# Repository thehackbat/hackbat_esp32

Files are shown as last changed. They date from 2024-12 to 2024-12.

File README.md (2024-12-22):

# HACKBAT ESP32 

New version of the Hackbat tool, this time based on the ESP32 C6. 

> NOTE: This version is still under test, so minor changes can be applied.

## The CPU

The new version of hackbat features a powerful [ESP32C6](https://www.espressif.com/en/products/socs/esp32-c6) from [Espressif](https://www.espressif.com). This microcontroller features a dual core RISC-V processor, WIFI6, BT LE and a bunch of peripherals. 

The package used is the WROOM-1, but it is also compatible with the 1U model adding an external antenna.

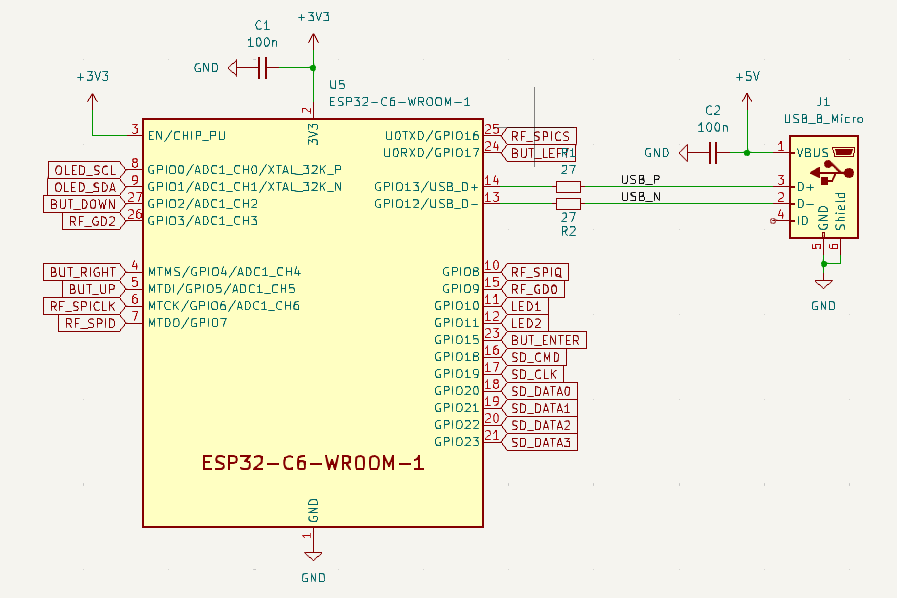
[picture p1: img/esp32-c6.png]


## RF

Like the original, the Hackbat ESP32 features an RF tranceiver, the [CC1101](https://www.ti.com/product/es-mx/CC1101) from Texas Instruments. 

The CC1101 is a low-cost sub-1 GHz transceiver designed for very low-power wireless applications. The circuit is mainly intended for the ISM (Industrial, Scientific and Medical) and SRD (Short Range Device) frequency bands at 315, 433, 868, and 915 MHz, but can easily be programmed for operation at other frequencies in the 300-348 MHz, 387-464 MHz and 779-928 MHz bands

The Hackbat ESP32 board includes an antenna, but can be also populate the J2 connector in order to add an SMA antenna.

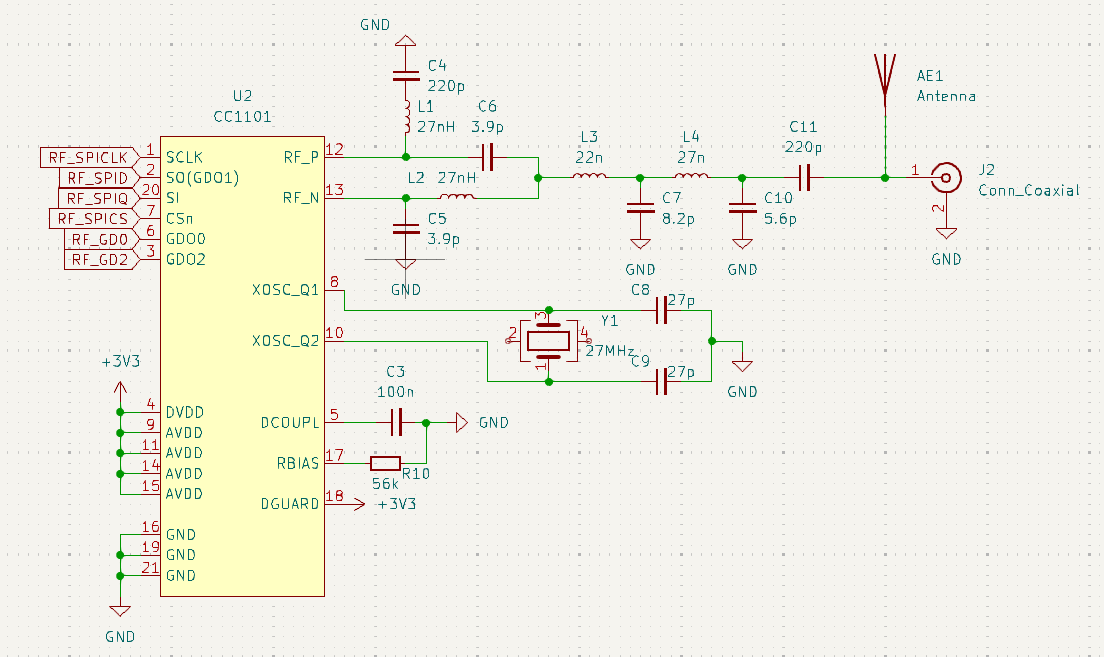
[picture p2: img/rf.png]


## OLED

A monochrome OLED is added as an interface. The driver used in the ESP-IDF IDE is able to work with the SH1106, and ssd1306

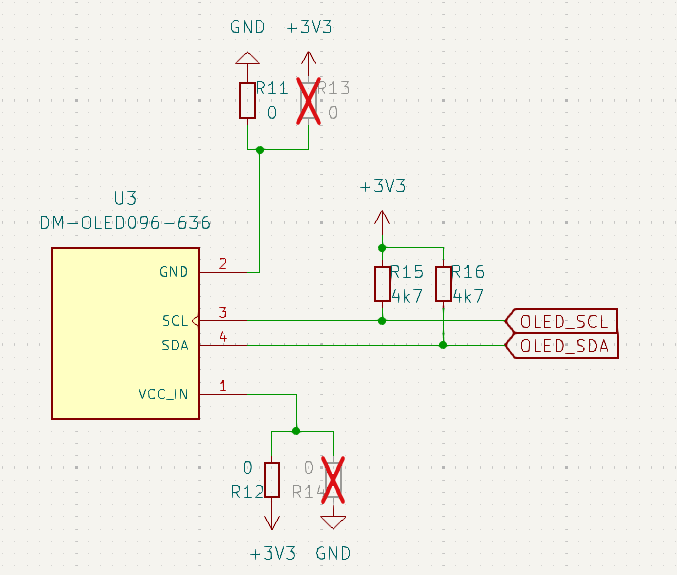
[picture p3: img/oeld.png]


## SDCard

The SD Card in this version uses the SDIO interface with the microcontroller, so the speed is increased with respect the first version of the board.

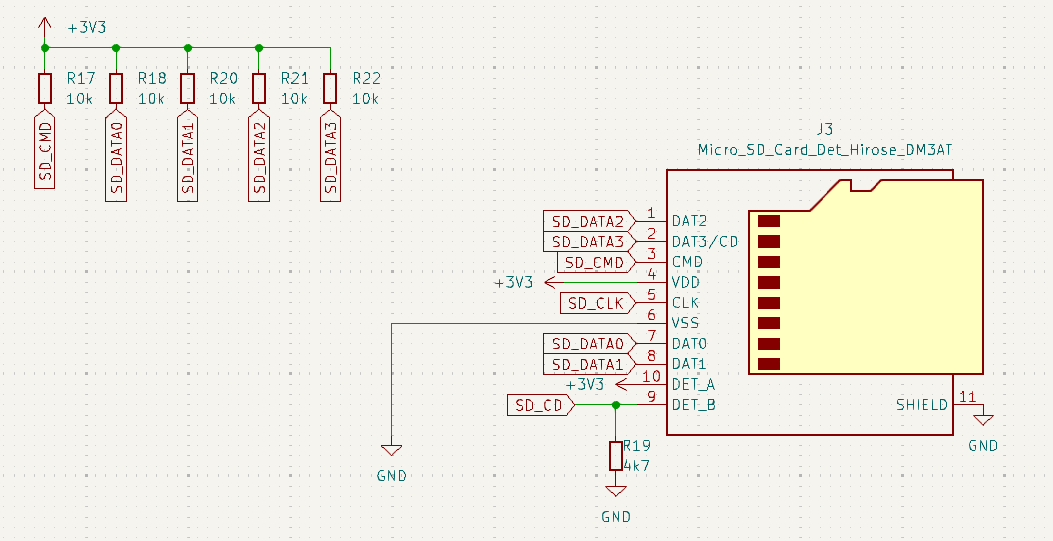
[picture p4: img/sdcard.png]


## Layout

The layout of the board is 2-layer with components in both layers.

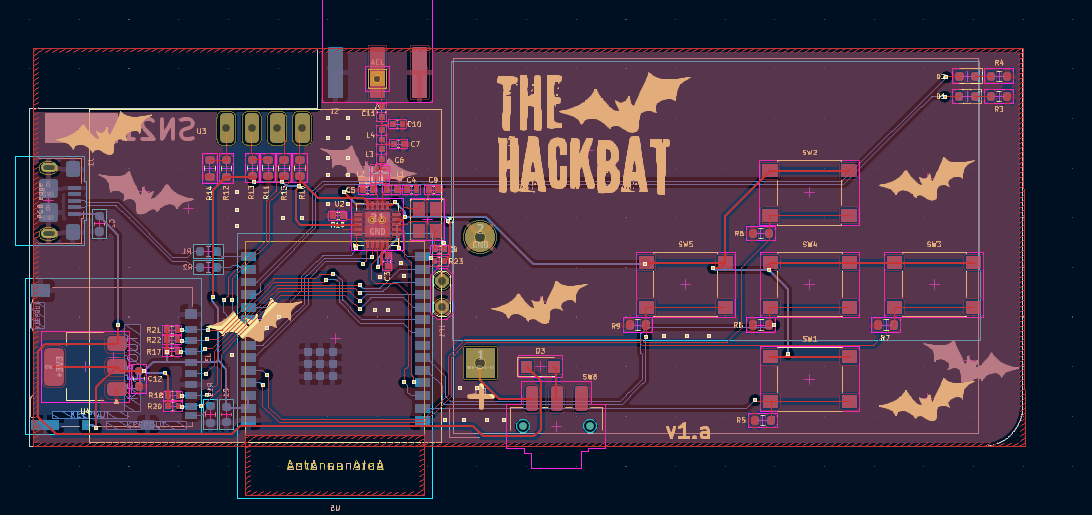
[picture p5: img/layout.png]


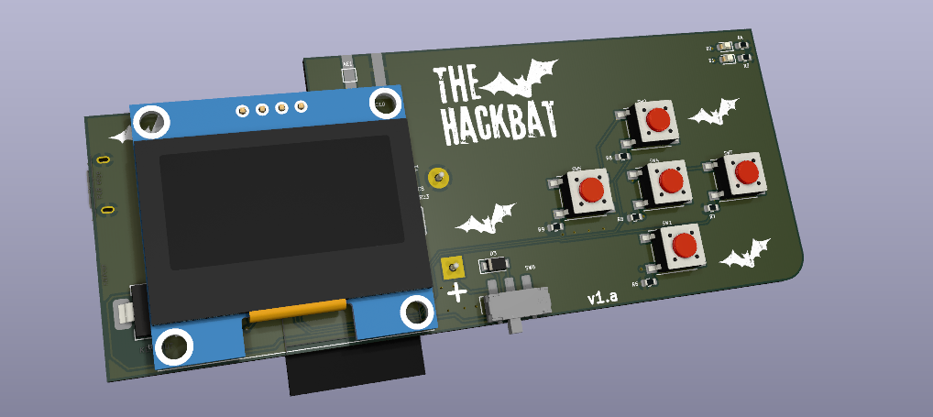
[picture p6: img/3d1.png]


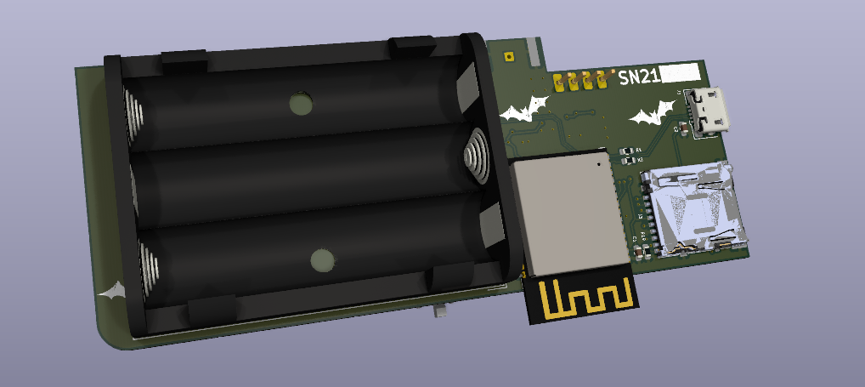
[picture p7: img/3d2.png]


## Get yours

This project is open-source so you can build your own Hackbat by sending the production files to [JLCPCB](https://jlcpcb.com/?from=controlpath).

[JLCPCB](https://jlcpcb.com/?from=controlpath) not only will manufacture your PCB, but they can also asembly your board. To do that, you have to use the BOM and the Centroid files provided in the [`production_files`](./kicad/production_files/) folder.

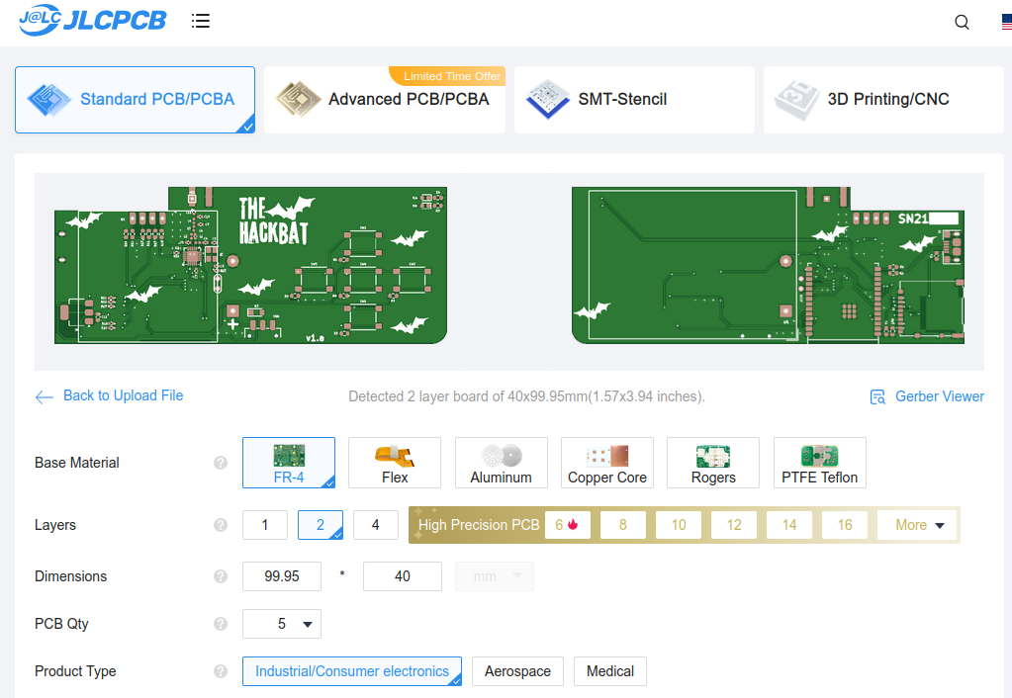
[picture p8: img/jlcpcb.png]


Remember to change the Surface Finish to LeadFree HASL to make your board ROHS compliant. Also, the original board uses a Black PCB color, so if you want to keep your Hackbat like the original, you can select this color to be sure that the silkscreen is seen correctly.

In a few days, you will receive your board at home.

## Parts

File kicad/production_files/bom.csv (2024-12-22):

Reference | Value | Footprint | Qty | DNP | JLCPCB Part #
C1,C2 | 100n | Capacitor_SMD:C_0603_1608Metric | 2
C3 | 100n | Capacitor_SMD:C_0402_1005Metric | 1
C4,C11 | 220p | Capacitor_SMD:C_0402_1005Metric | 2
C5,C6 | 3.9p | Capacitor_SMD:C_0402_1005Metric | 2
C7 | 8.2p | Capacitor_SMD:C_0402_1005Metric | 1
C8,C9 | 27p | Capacitor_SMD:C_0402_1005Metric | 2
C10 | 5.6p | Capacitor_SMD:C_0402_1005Metric | 1
C12 | 1u | Capacitor_SMD:C_0603_1608Metric | 1
D1,D2 | LED | LED_SMD:LED_0603_1608Metric | 2
D3 | D_Schottky | Diode_SMD:Nexperia_CFP3_SOD-123W | 1 |  | C82544
J1 | USB_B_Micro | Connector_USB:USB_Micro-B_Amphenol_10118193-0001LF_Horizontal | 1
J2 | Conn_Coaxial | Connector_Coaxial:SMA_Amphenol_132289_EdgeMount | 1
J3 | Micro_SD_Card_Det_Hirose_DM3AT | Connector_Card:microSD_HC_Hirose_DM3AT-SF-PEJM5 | 1 |  | C114218
JP1 | Jumper_2_Open | TestPoint:TestPoint_2Pads_Pitch2.54mm_Drill0.8mm | 1
L1,L2 | 27nH | Inductor_SMD:L_0402_1005Metric | 2
L3 | 22n | Inductor_SMD:L_0402_1005Metric | 1
L4 | 27n | Inductor_SMD:L_0402_1005Metric | 1
R1,R2 | 27 | Resistor_SMD:R_0603_1608Metric | 2
R3,R4,R5,R6,R7,R8,R9,R15,R16,R19 | 4k7 | Resistor_SMD:R_0603_1608Metric | 10
R10 | 56k | Resistor_SMD:R_0402_1005Metric | 1
R11,R12 | 0 | Resistor_SMD:R_0603_1608Metric | 2
R17,R18,R20,R21,R22,R23 | 10k | Resistor_SMD:R_0402_1005Metric | 6
SW1,SW2,SW3,SW4,SW5 | SW_Push | Button_Switch_SMD:SW_Push_1P1T_NO_6x6mm_H9.5mm | 5 |  | C455109
SW6 | SW_SPST | Button_Switch_SMD:SW_SPDT_CK_JS102011SAQN | 1 |  | C92658
U2 | CC1101 | Package_DFN_QFN:QFN-20-1EP_4x4mm_P0.5mm_EP2.6x2.6mm_ThermalVias | 1 |  | C29953
U4 | AMS1117-3.3 | Package_TO_SOT_SMD:SOT-223-3_TabPin2 | 1
Y1 | 27MHz | Crystal:Crystal_SMD_3225-4Pin_3.2x2.5mm | 1 |  | C254353

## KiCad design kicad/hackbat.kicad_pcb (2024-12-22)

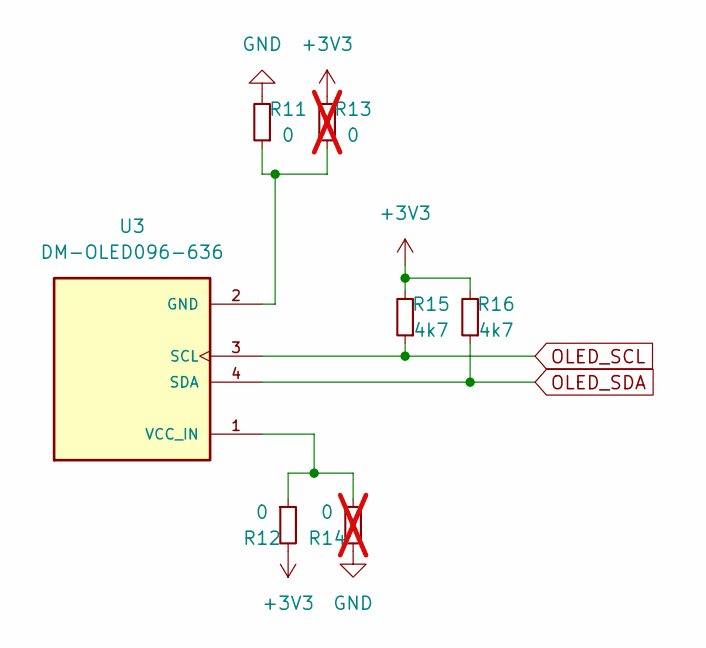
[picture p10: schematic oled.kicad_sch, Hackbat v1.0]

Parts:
R11, R12: 0; R_0603_1608Metric
R13, R14: 0; R_0603_1608Metric; not fitted
R15, R16: 4k7; R_0603_1608Metric
U3: DM-OLED096-636; oled_1.3; PARTREV 2018-09-10

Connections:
+3V3: R12.2, R13.2, R15.2, R16.2; also elsewhere on the board
GND: R11.2, R14.2; also elsewhere on the board
unnamed: R11.1, R13.1, U3.2 (GND)
unnamed: R12.1, R14.1, U3.1 (VCC_IN)
OLED_SCL: R15.1, U3.3 (SCL); also elsewhere on the board
OLED_SDA: R16.1, U3.4 (SDA); also elsewhere on the board

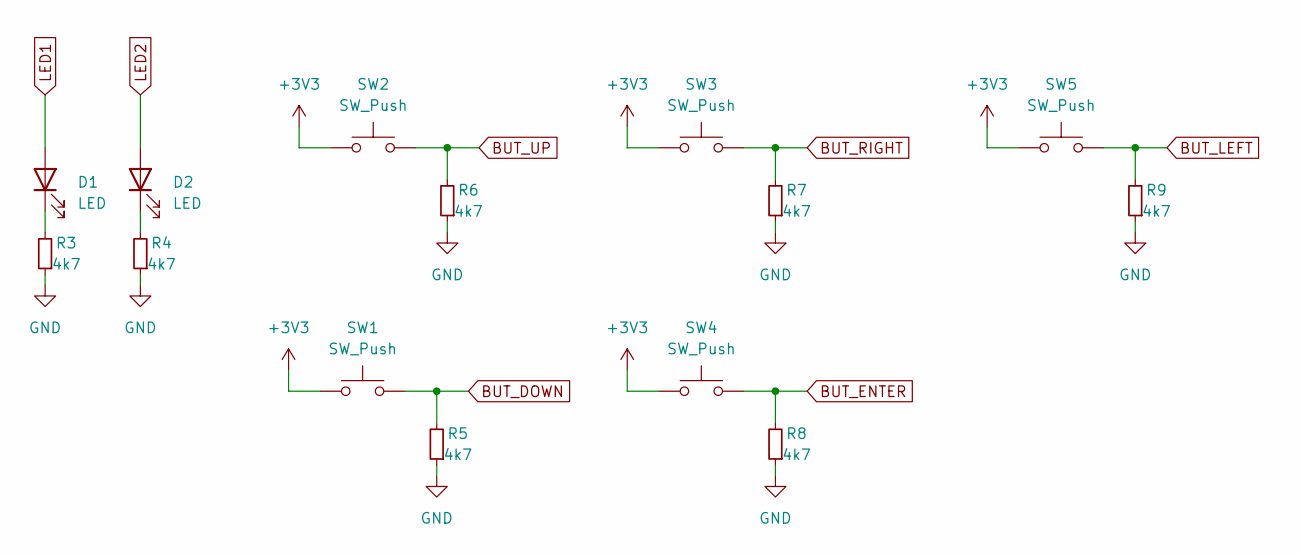
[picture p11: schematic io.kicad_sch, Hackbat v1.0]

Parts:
D1, D2: LED; LED_0603_1608Metric
R3, R4, R5, R6, R7, R8, R9: 4k7; R_0603_1608Metric
SW1, SW2, SW3, SW4, SW5: SW_Push; SW_Push_1P1T_NO_6x6mm_H9.5mm; JLCPCB Part # C455109

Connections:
+3V3: SW1.1, SW2.1, SW3.1, SW4.1, SW5.1; also elsewhere on the board
BUT_DOWN: R5.2, SW1.2; also elsewhere on the board
BUT_ENTER: R8.2, SW4.2; also elsewhere on the board
BUT_LEFT: R9.2, SW5.2; also elsewhere on the board
BUT_RIGHT: R7.2, SW3.2; also elsewhere on the board
BUT_UP: R6.2, SW2.2; also elsewhere on the board
GND: R3.1, R4.1, R5.1, R6.1, R7.1, R8.1, R9.1; also elsewhere on the board
LED1: D1.2 (A); also elsewhere on the board
LED2: D2.2 (A); also elsewhere on the board
unnamed: D1.1 (K), R3.2
unnamed: D2.1 (K), R4.2

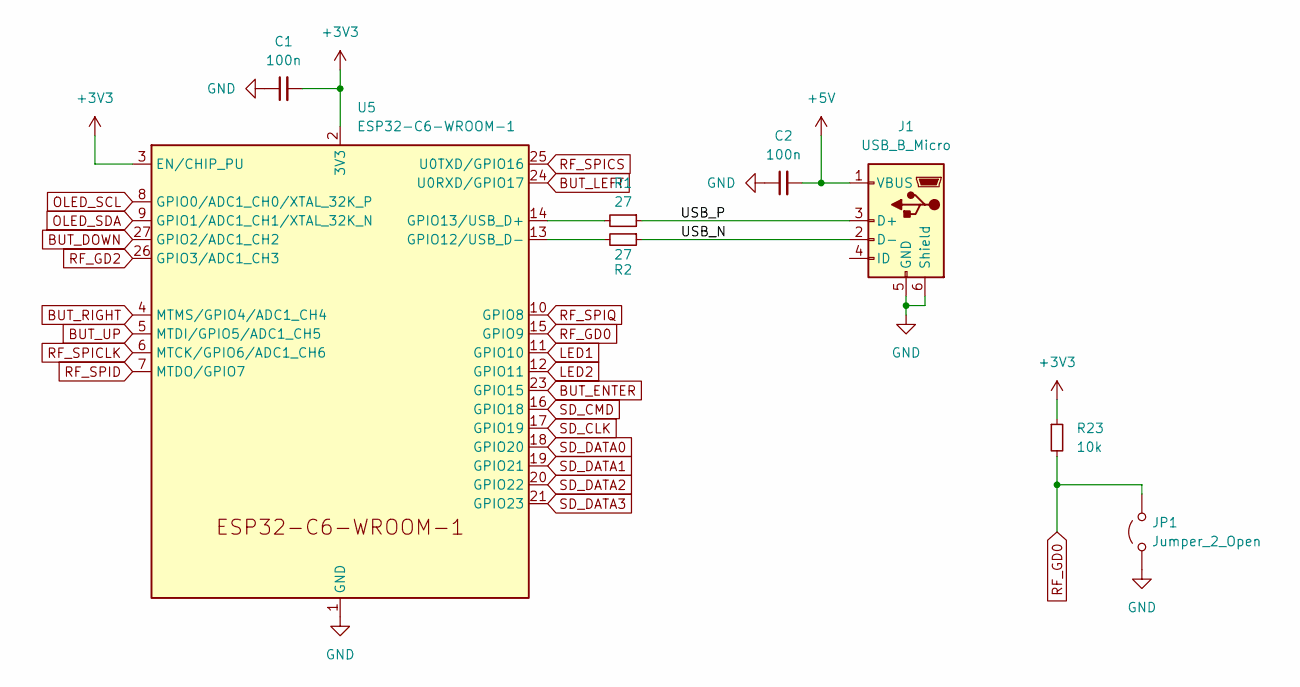
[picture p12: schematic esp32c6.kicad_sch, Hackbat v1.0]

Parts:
C1, C2: 100n; C_0603_1608Metric
J1: USB_B_Micro; USB_Micro-B_Amphenol_10118193-0001LF_Horizontal
JP1: Jumper_2_Open; TestPoint_2Pads_Pitch2.54mm_Drill0.8mm
R1, R2: 27; R_0603_1608Metric
R23: 10k; R_0402_1005Metric
U5: ESP32-C6-WROOM-1

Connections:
+3V3: C1.2, R23.1, U5.2 (3V3), U5.3 (EN/CHIP_PU); also elsewhere on the board
+5V: C2.2, J1.1 (VBUS); also elsewhere on the board
/esp32c6/USB_N: J1.2 (D-), R2.1
/esp32c6/USB_P: J1.3 (D+), R1.1
BUT_DOWN: U5.27 (GPIO2/ADC1_CH2); also elsewhere on the board
BUT_ENTER: U5.23 (GPIO15); also elsewhere on the board
BUT_LEFT: U5.24 (U0RXD/GPIO17); also elsewhere on the board
BUT_RIGHT: U5.4 (MTMS/GPIO4/ADC1_CH4); also elsewhere on the board
BUT_UP: U5.5 (MTDI/GPIO5/ADC1_CH5); also elsewhere on the board
GND: C1.1, C2.1, J1.5 (GND), J1.6 (Shield), JP1.1 (A), U5.1 (GND), U5.28 (GND), U5.29 (GND); also elsewhere on the board
LED1: U5.11 (GPIO10); also elsewhere on the board
LED2: U5.12 (GPIO11); also elsewhere on the board
unnamed: R2.2, U5.13 (GPIO12/USB_D-)
unnamed: R1.2, U5.14 (GPIO13/USB_D+)
OLED_SCL: U5.8 (GPIO0/ADC1_CH0/XTAL_32K_P); also elsewhere on the board
OLED_SDA: U5.9 (GPIO1/ADC1_CH1/XTAL_32K_N); also elsewhere on the board
RF_GD0: JP1.2 (B), R23.2, U5.15 (GPIO9); also elsewhere on the board
RF_GD2: U5.26 (GPIO3/ADC1_CH3); also elsewhere on the board
RF_SPICLK: U5.6 (MTCK/GPIO6/ADC1_CH6); also elsewhere on the board
RF_SPICS: U5.25 (U0TXD/GPIO16); also elsewhere on the board
RF_SPID: U5.7 (MTDO/GPIO7); also elsewhere on the board
RF_SPIQ: U5.10 (GPIO8); also elsewhere on the board
SD_CLK: U5.17 (GPIO19); also elsewhere on the board
SD_CMD: U5.16 (GPIO18); also elsewhere on the board
SD_DATA0: U5.18 (GPIO20); also elsewhere on the board
SD_DATA1: U5.19 (GPIO21); also elsewhere on the board
SD_DATA2: U5.20 (GPIO22); also elsewhere on the board
SD_DATA3: U5.21 (GPIO23); also elsewhere on the board

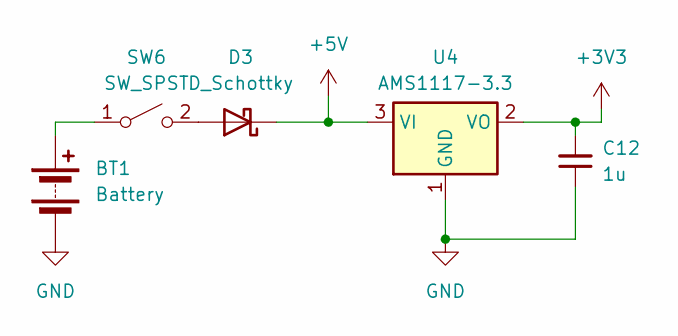
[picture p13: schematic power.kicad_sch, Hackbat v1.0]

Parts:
BT1: Battery; BatteryHolder_Keystone_2479_3xAAA
C12: 1u; C_0603_1608Metric
D3: D_Schottky; Nexperia_CFP3_SOD-123W; JLCPCB Part # C82544
SW6: SW_SPST; SW_SPDT_CK_JS102011SAQN; JLCPCB Part # C92658
U4: AMS1117-3.3; SOT-223-3_TabPin2

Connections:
+3V3: C12.2, U4.2 (VO); also elsewhere on the board
+5V: D3.1 (K), U4.3 (VI); also elsewhere on the board
GND: BT1.2 (-), C12.1, U4.1 (GND); also elsewhere on the board
unnamed: BT1.1 (+), SW6.1 (A)
unnamed: D3.2 (A), SW6.2 (B)

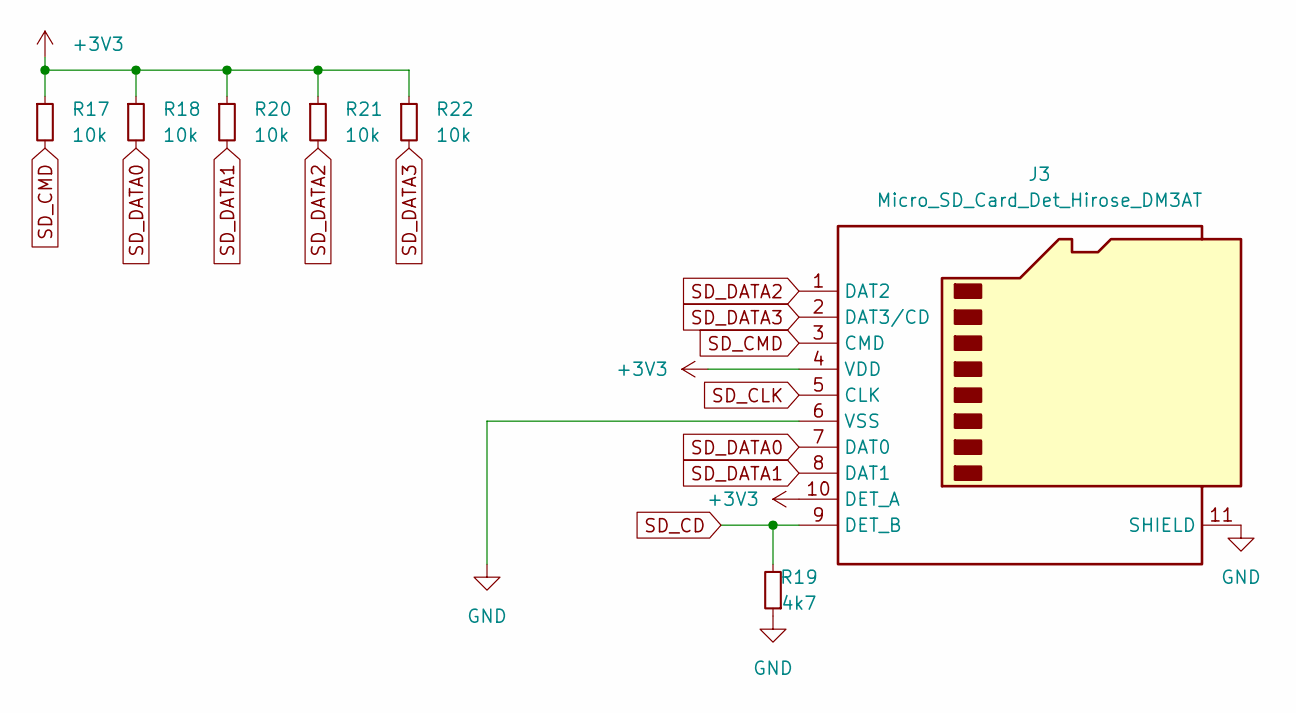
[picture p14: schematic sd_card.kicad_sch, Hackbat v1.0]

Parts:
J3: Micro_SD_Card_Det_Hirose_DM3AT; microSD_HC_Hirose_DM3AT-SF-PEJM5; JLCPCB Part # C114218
R17, R18, R20, R21, R22: 10k; R_0402_1005Metric
R19: 4k7; R_0603_1608Metric

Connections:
+3V3: J3.4 (VDD), J3.10 (DET_A), R17.1, R18.1, R20.1, R21.1, R22.1; also elsewhere on the board
GND: J3.6 (VSS), J3.11 (SHIELD), R19.1; also elsewhere on the board
SD_CD: J3.9 (DET_B), R19.2
SD_CLK: J3.5 (CLK); also elsewhere on the board
SD_CMD: J3.3 (CMD), R17.2; also elsewhere on the board
SD_DATA0: J3.7 (DAT0), R18.2; also elsewhere on the board
SD_DATA1: J3.8 (DAT1), R20.2; also elsewhere on the board
SD_DATA2: J3.1 (DAT2), R21.2; also elsewhere on the board
SD_DATA3: J3.2 (DAT3/CD), R22.2; also elsewhere on the board

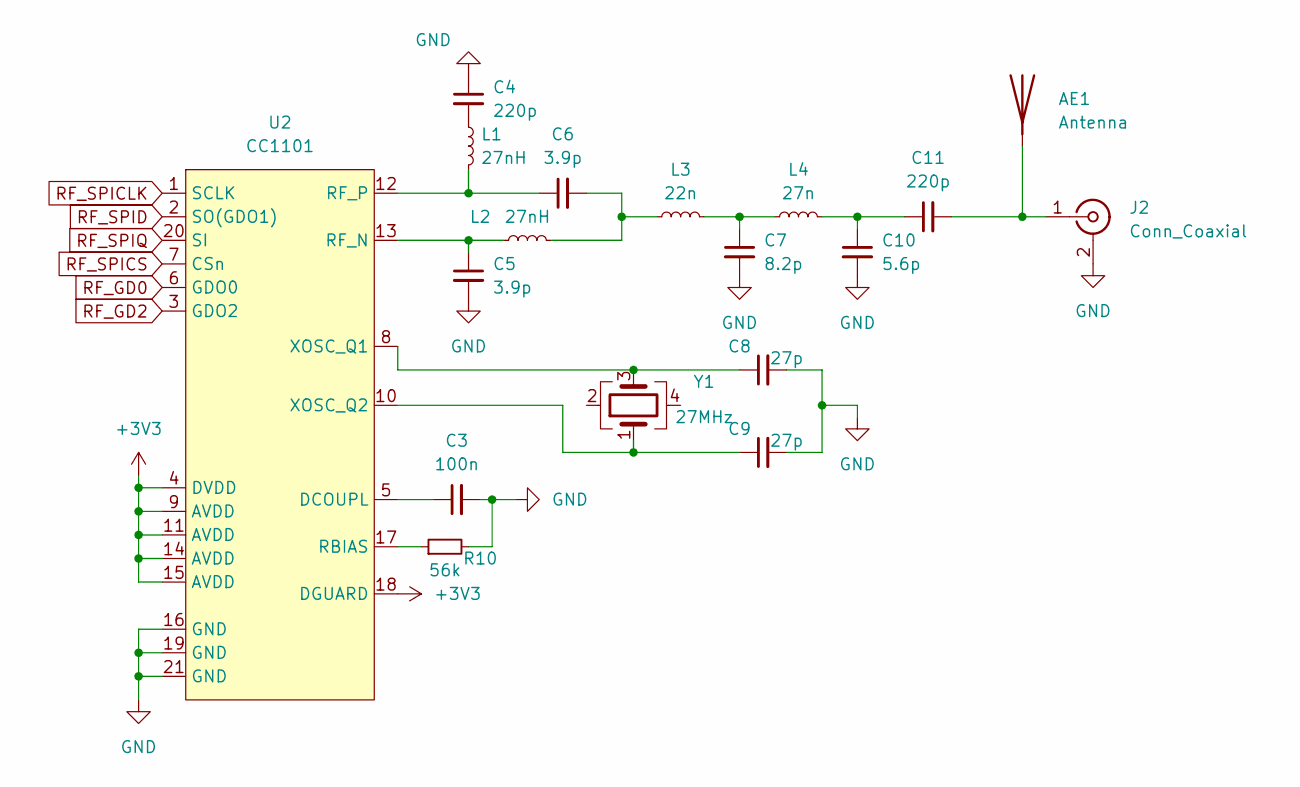
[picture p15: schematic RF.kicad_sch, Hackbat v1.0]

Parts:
AE1: Antenna; TestPoint_THTPad_1.5x1.5mm_Drill0.7mm
C3: 100n; C_0402_1005Metric
C4, C11: 220p; C_0402_1005Metric
C5, C6: 3.9p; C_0402_1005Metric
C7: 8.2p; C_0402_1005Metric
C8, C9: 27p; C_0402_1005Metric
C10: 5.6p; C_0402_1005Metric
J2: Conn_Coaxial; SMA_Amphenol_132289_EdgeMount
L1, L2: 27nH; L_0402_1005Metric
L3: 22n; L_0402_1005Metric
L4: 27n; L_0402_1005Metric
R10: 56k; R_0402_1005Metric
U2: CC1101; QFN-20-1EP_4x4mm_P0.5mm_EP2.6x2.6mm_ThermalVias; JLCPCB Part # C29953
Y1: 27MHz; Crystal_SMD_3225-4Pin_3.2x2.5mm; JLCPCB Part # C254353

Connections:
+3V3: U2.4 (DVDD), U2.9 (AVDD), U2.11 (AVDD), U2.14 (AVDD), U2.15 (AVDD), U2.18 (DGUARD); also elsewhere on the board
GND: C3.2, C4.1, C5.2, C7.2, C8.2, C9.2, C10.2, J2.2 (Ext), R10.2, U2.16 (GND), U2.19 (GND), U2.21 (GND); also elsewhere on the board
unnamed: AE1.1 (A), C11.2, J2.1 (In)
unnamed: C4.2, L1.1
unnamed: C6.2, L2.2, L3.1
unnamed: C7.1, L3.2, L4.1
unnamed: C10.1, C11.1, L4.2
unnamed: C3.1, U2.5 (DCOUPL)
unnamed: R10.1, U2.17 (RBIAS)
unnamed: C5.1, L2.1, U2.13 (RF_N)
unnamed: C6.1, L1.2, U2.12 (RF_P)
unnamed: C8.1, U2.8 (XOSC_Q1), Y1.3
unnamed: C9.1, U2.10 (XOSC_Q2), Y1.1
RF_GD0: U2.6 (GDO0); also elsewhere on the board
RF_GD2: U2.3 (GDO2); also elsewhere on the board
RF_SPICLK: U2.1 (SCLK); also elsewhere on the board
RF_SPICS: U2.7 (CSn); also elsewhere on the board
RF_SPID: U2.2 (SO(GDO1)); also elsewhere on the board
RF_SPIQ: U2.20 (SI); also elsewhere on the board

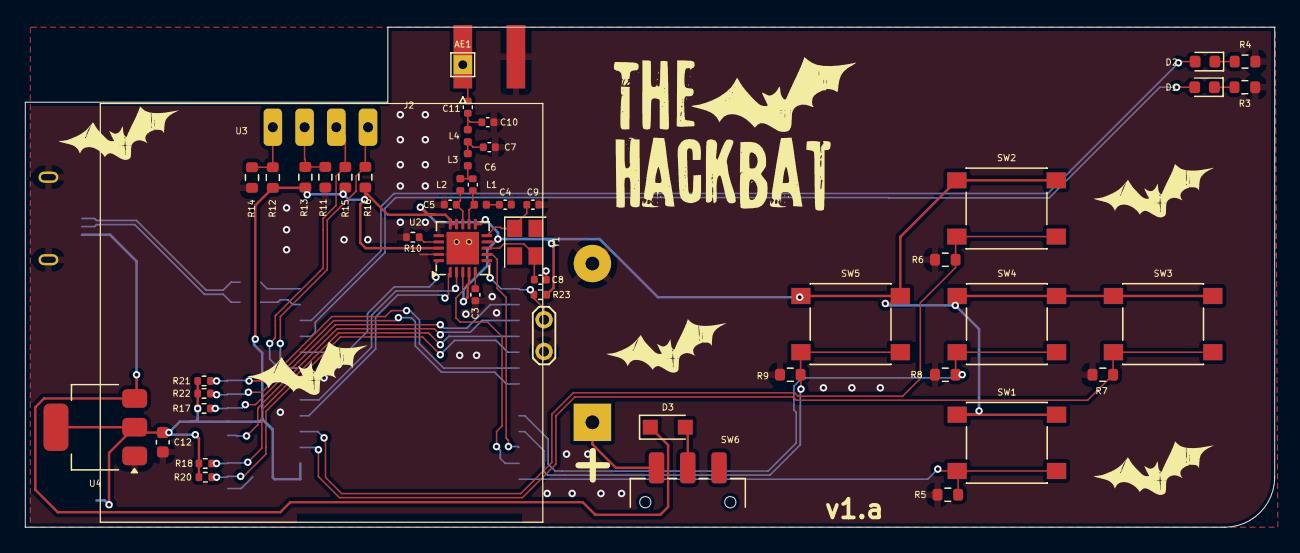
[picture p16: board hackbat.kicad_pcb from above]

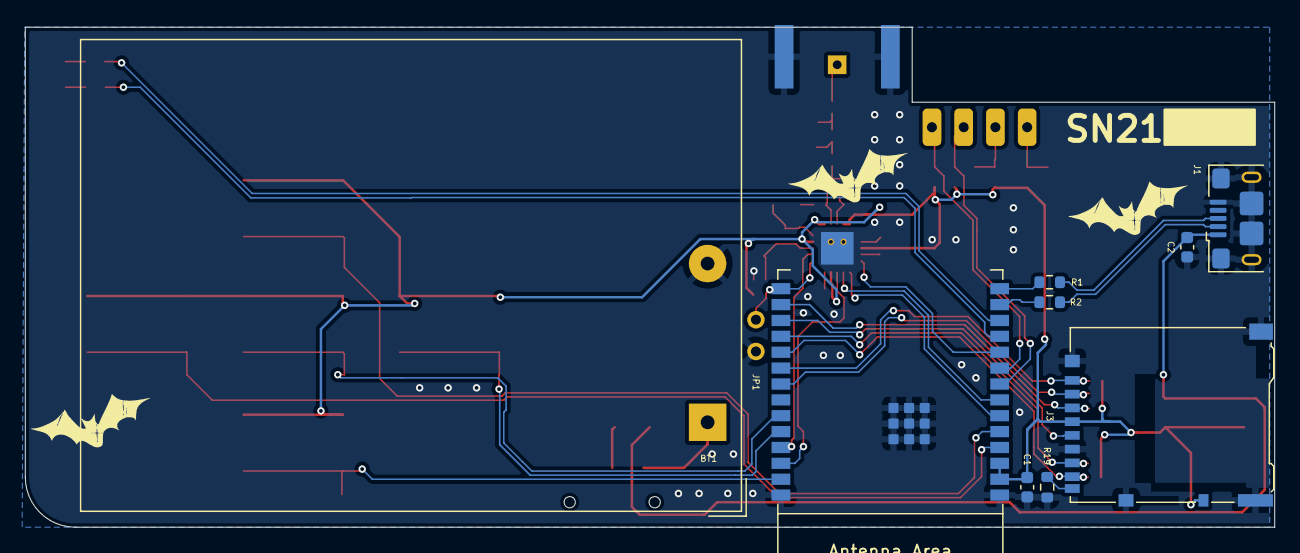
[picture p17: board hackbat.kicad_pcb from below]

Board: 2 copper layers, 99.9 x 40.0 mm, 59 parts (9 on the bottom side), 46 nets.
